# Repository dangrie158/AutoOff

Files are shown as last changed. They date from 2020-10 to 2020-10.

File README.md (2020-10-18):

# AutoOff

A simple timer slightly smarter than a 555 to control 2 individual relays to automatically power off devices after a given amount of time with a single switch.

You can configure the timeout by adjusting the variable `powerOnTime` in the Firmware.

By default a single click on the button will switch on the relays and start the timer.
If the button is pressed again, the timer is stoppend and the relays are opened.
If, however, the button is double-clicked while the relays are on, the timer restarts again.

The PCB is designed for a maximum current flow of 5A / channel, however if you don't need that much current in your application, you should use fuses with a lower, more apropriate rating.

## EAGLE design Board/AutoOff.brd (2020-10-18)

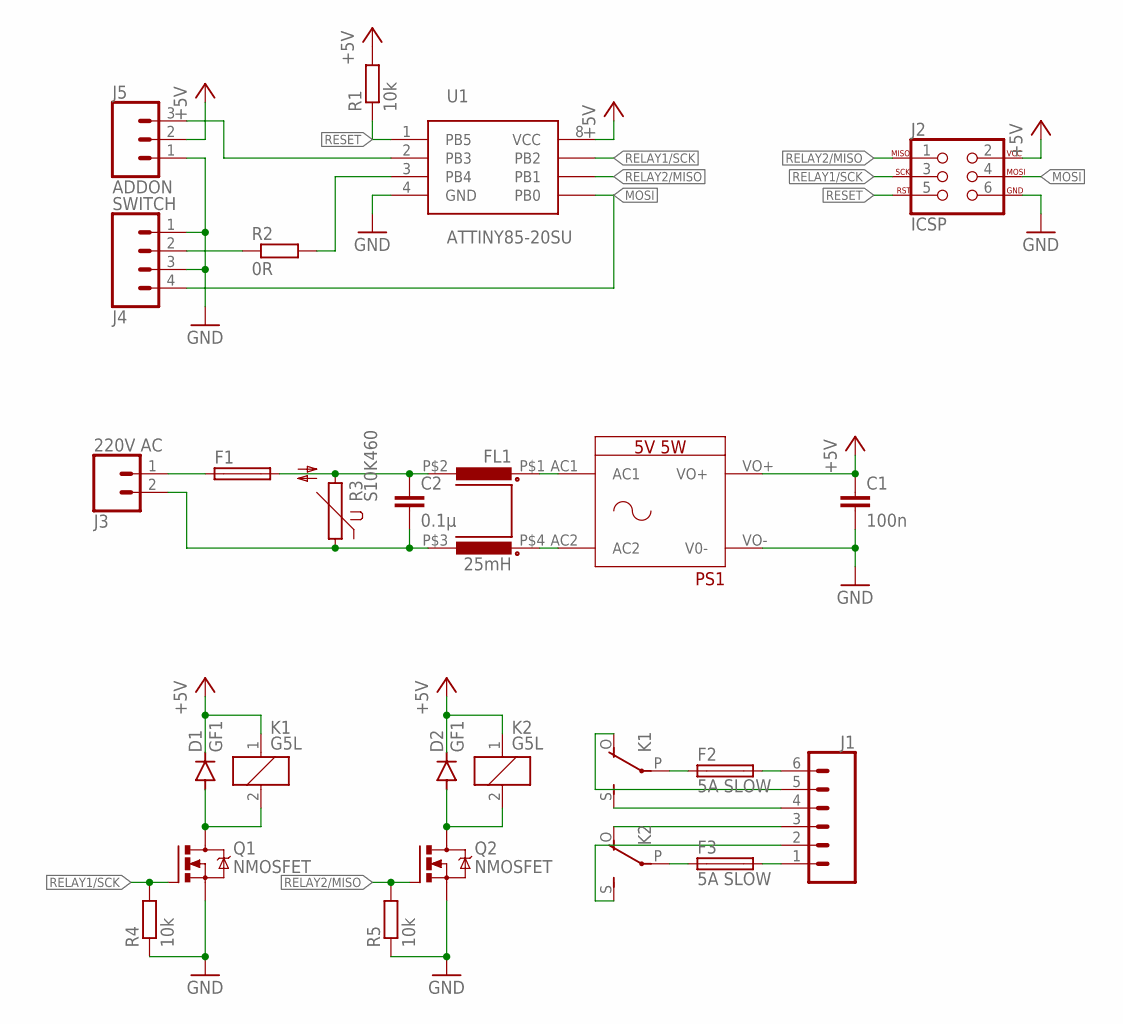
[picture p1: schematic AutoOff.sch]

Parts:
C1: 100n; C0603
C2: 0.1µ; C102-064X133
D1, D2: GF1; SMA-DO214AC
F1: 0.5A SLOW; SH22,5A
F2, F3: 5A SLOW; SH22,5A
FL1: 25mH; UU9.8-YH161014
J1: CONN_063.5MM-6; SCREWTERMINAL-3.5MM-6
J2: ICSP; 2X3_LOCK
J3: 220V AC; SCREWTERMINAL-3.5MM-2_LOCK
J4: SWITCH; SCREWTERMINAL-3.5MM-4_LOCK
J5: ADDON; SCREWTERMINAL-3.5MM-3_LOCK.007S
K1, K2: G5L; G5LE
PS1: 5V 5W; HLK-5M
Q1, Q2: NMOSFET; SOT23
R1, R4, R5: 10k; R0603
R2: 0R; R0603
R3: S10K460
U1: ATTINY85-20SU; SOIC-8

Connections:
+5V: C1.1, D1.K (C), D2.K (C), J2.2, J5.2, K1.1, K2.1, PS1.VO+, R1.2, U1.8 (VCC)
GND: C1.2, J2.6, J4.1, J4.3, J5.1, PS1.VO- (V0-), Q1.2 (S), Q2.2 (S), R4.1, R5.1, U1.4 (GND)
MOSI: J2.4, J4.4, U1.5 (PB0)
unnamed: J1.3, K2.O
unnamed: F3.1, K2.P
unnamed: F3.2, J1.1
unnamed: F2.1, K1.P
unnamed: J1.4, K1.S
unnamed: F2.2, J1.6
unnamed: J1.2, K2.S
unnamed: J1.5, K1.O
unnamed: FL1.P$1 (1), PS1.AC1
unnamed: D1.A, K1.2, Q1.3 (D)
unnamed: FL1.P$4 (4), PS1.AC2
unnamed: D2.A, K2.2, Q2.3 (D)
unnamed: J4.2, R2.1
unnamed: R2.2, U1.3 (PB4)
unnamed: J5.3, U1.2 (PB3)
unnamed: F1.1, J3.1
unnamed: C2.2, FL1.P$3 (3), J3.2, R3.1
unnamed: C2.1, F1.2, FL1.P$2 (2), R3.2
RELAY1/SCK: J2.3, Q1.1 (G), R4.2, U1.7 (PB2)
RELAY2/MISO: J2.1, Q2.1 (G), R5.2, U1.6 (PB1)
RESET: J2.5, R1.1, U1.1 (PB5)

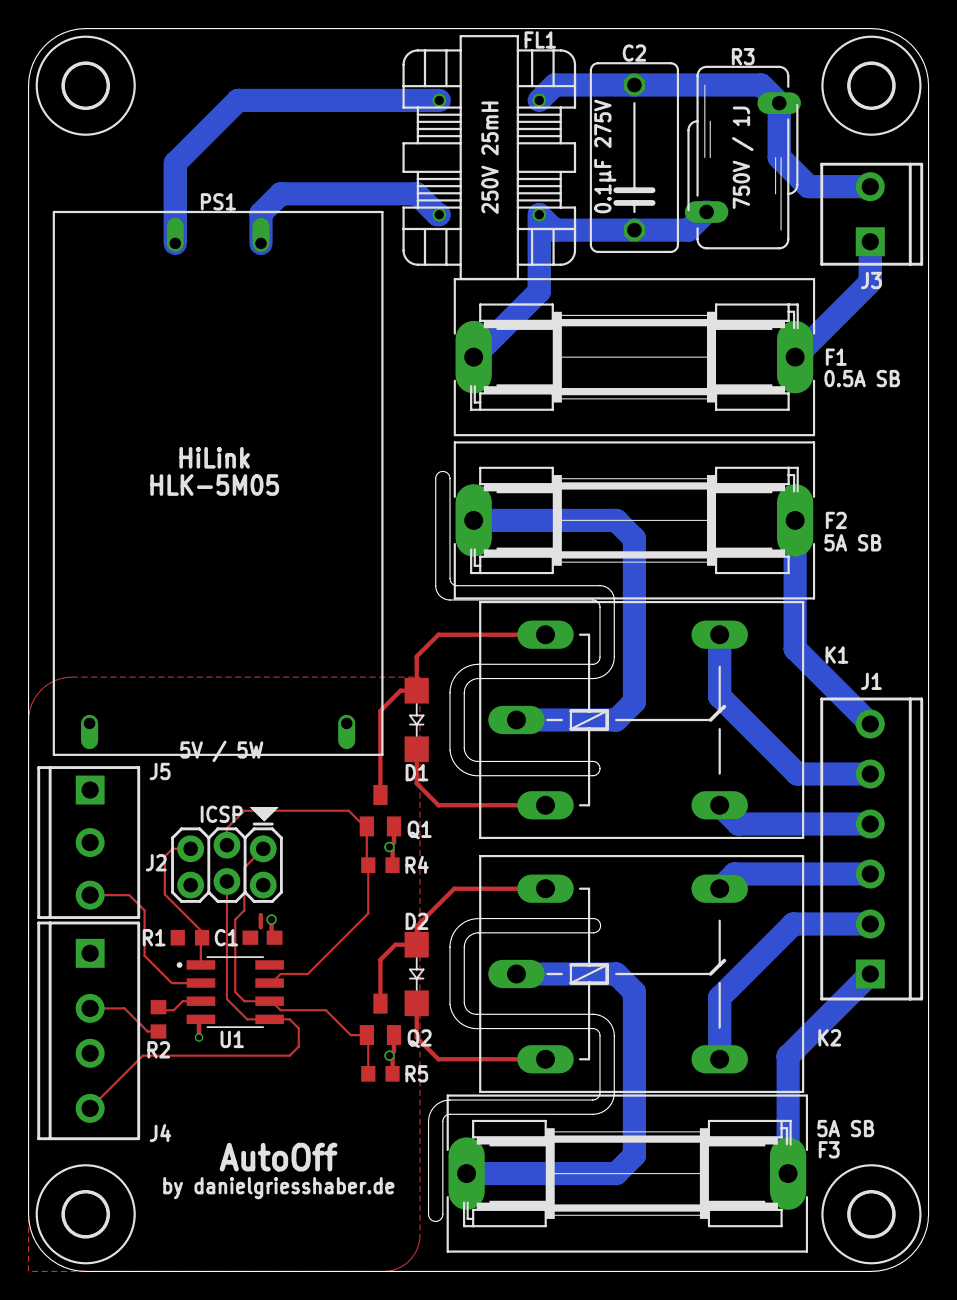
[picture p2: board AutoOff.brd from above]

Board: 2 copper layers, 63.0 x 87.0 mm, 28 parts (0 on the bottom side), 24 nets.

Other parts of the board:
U$1, U$2, U$3, U$4: 3,0

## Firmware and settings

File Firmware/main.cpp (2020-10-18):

#include <stdint.h>
#include <stdlib.h>
#include <stdbool.h>

#include <util/delay.h>
#include <avr/interrupt.h>
#include <avr/io.h>

#include "io.h"

//time the relays will be energized before powering off again
const uint16_t powerOnTime = 60 * 60 * 5;

// time in ms to wait before re-registering a button press for debouncing
const uint8_t debounceDelay = 100;

//time the relays will still be energized (in seconds)
volatile uint16_t timeUntilPowerDown = 0;
volatile bool btnPressed = false;

avr::Input button(avr::PortB, PB0, true, true);
avr::Output relay2(avr::PortB, PB1);
avr::Output relay1(avr::PortB, PB2);
avr::Output addon(avr::PortB, PB3);
avr::Output led(avr::PortB, PB4);

void setupTimer1()
{
    // Setup the Timer1 to fire once a second
    cli();
    // prescaler = FCPU / 16384 ~= 61Hz
    // CTC - clear on compare match with OCR1C
    TCCR1 |= (1 << CTC1);
    TCCR1 |= (1 << CS10) | (1 << CS11) | (1 << CS12) | (1 << CS13);

    // (F_CPU / PRESCALER ) / 1Hz ~= 61
    OCR1A = 61;
    OCR1C = OCR1A;

    // Output Compare Match A Interrupt Enable
    TIMSK |= (1 << OCIE1A);

    // enable interrupts
    sei();
}

void setupInterrupt()
{
    cli();
    // pin change interrupt enable
    GIMSK |= (1 << PCIE);

    // pin change interrupt enabled for PCINT4
    PCMSK |= (1 << PCINT0);

    // enable interrupts
    sei();
}

void debounceButton()
{
    //wait fo the debounce delay before resetting the button state
    _delay_ms(debounceDelay);
    btnPressed = false;
}

int main()
{
    setupTimer1();
    setupInterrupt();

    while (true)
    {
        if (btnPressed)
        {
            if (timeUntilPowerDown == 0)
            {
                // outputs were off, time to switch them on
                led << 1;
                relay1 << 1;
                relay2 << 1;
                timeUntilPowerDown = powerOnTime;
            }
            else
            {
                //switch off the led to indicate we registered the press
                led << 0;
                // outputs are on. start a countdown for power off
                timeUntilPowerDown = 2;

                debounceButton();

                // if the button is pressed again in the next second
                // this was a double press, so rearm the timer
                _delay_ms(1000);
                if (btnPressed)
                {
                    led << 1;
                    timeUntilPowerDown = powerOnTime;
                }
                else
                {
                    //it was not a double-press so interpret it as
                    //a request to power down. (the next if statement
                    // will actually handle the power-down so we don't
                    // need to to anything here)
                }
            }
            debounceButton();
        }

        if (timeUntilPowerDown == 0)
        {
            led << 0;
            relay1 << 0;
            relay2 << 0;
        }
    }
}

ISR(PCINT0_vect)
{
    //only trigger on a high-level of the button
    if (button)
    {
        btnPressed = true;
    }
}

ISR(TIMER1_COMPA_vect)
{
    //decrement the coundown timer
    if (timeUntilPowerDown > 0)
    {
        timeUntilPowerDown--;
    }
}

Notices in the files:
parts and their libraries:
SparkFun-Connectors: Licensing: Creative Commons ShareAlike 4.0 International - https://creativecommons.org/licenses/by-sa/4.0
